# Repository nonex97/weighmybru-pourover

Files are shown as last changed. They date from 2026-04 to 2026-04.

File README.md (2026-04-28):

# WeighMyBru Pour-Over

A custom variant of the WeighMyBru² DIY espresso scale with a 1.3" SH1106 
OLED display, 3kg load cell, and a custom 3D printed enclosure.

## Documentation

📖 **[View the full documentation](https://nonex97.github.io/weighmybru-pourover/)**

For parts list, flashing guide, code changes, and print variations.

## Credits

- Original project by [031devstudios](https://weighmybru.com)
- SH1106 driver by [mlodedrwale](https://github.com/mlodedrwale/weighmybru2/tree/SH1106)

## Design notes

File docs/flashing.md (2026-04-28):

# Flashing Guide

## Prerequisites

Before starting, make sure you have the following ready:

✅ VSCode installed

✅ PlatformIO extension installed

✅ Seeed Studio XIAO ESP32S3

✅ USB-C cable (data-capable, not charge-only)

---

## Step 1 — Install Git

=== "Windows"
    Download Git from [git-scm.com](https://git-scm.com/download/win)
    and run the installer with default settings. Then verify in PowerShell:

    ```powershell
    git --version
    ```

=== "macOS"
    Using Homebrew
    ```bash
    brew install git
    ```
    Or download from [git-scm.com](https://git-scm.com/install/mac)

=== "Linux (Ubuntu/Debian)"
    
    ```bash
    sudo apt update && sudo apt install git
    ```

---

## Step 2 — Clone the Repository

Open a terminal and run:

```powershell
cd ~/Documents # or wherever you keep projects
```
```
mkdir esp32-projects
```
```
git clone -b SH1106 https://github.com/mlodedrwale/weighmybru2.git
```
```
cd weighmybru2

```

---

## Step 3 — Open in VSCode with PlatformIO

1. Launch VSCode
2. Go to **File → Open Folder**
3. Navigate to and select the `weighmybru2` folder you just cloned
4. Click **Select Folder**
5. Wait for PlatformIO to initialize — you'll see activity in the bottom status bar

---

## Step 4 — Configure `platformio.ini`

Check that the `platformio.ini` in the root of the project matches this:

```ini
[env:esp32-s3-devkitc-1]
platform = espressif32@6.12.0
board = esp32-s3-devkitc-1
framework = arduino
monitor_speed = 115200
board_upload.flash_size = 4MB
board_build.filesystem = littlefs
board_build.partitions = huge_app.csv
upload_protocol = esptool
upload_speed = 460800
upload_flags = 
	--chip=esp32s3
	--before=default_reset
	--after=hard_reset
monitor_rts = 0
monitor_dtr = 0
build_flags = 
	-DARDUINO_USB_CDC_ON_BOOT=1
	-DBOARD_HAS_PSRAM
	-Os
	-DCORE_DEBUG_LEVEL=0
lib_deps = 
	robtillaart/HX711@^0.6.0
	https://github.com/me-no-dev/ESPAsyncWebServer.git
	https://github.com/me-no-dev/AsyncTCP.git
	h2zero/NimBLE-Arduino@^1.4.0
	adafruit/Adafruit SSD1306@^2.5.7
	adafruit/Adafruit GFX Library@^1.11.9
	adafruit/Adafruit SH110X@^2.1.14
```

---
## Step 5 — Apply Code Changes

--8<-- "docs/code-changes.md"
---

## Step 6 — Connect the Board

1. Plug the XIAO ESP32S3 into your computer via USB-C
2. If the board isn't detected, put it into flash mode manually:
    - Hold **BOOT** while plugging in the USB
    - Press and release **RESET**
    - Release **BOOT**

---

## Step 7 — Find Your COM Port

In VSCode, check the **blue bottom status bar** — the COM port is listed there (e.g. `COM3` on Windows, "/dev/ttyUSB0" on Linux).

If it's not visible:

- **PlatformIO sidebar** → Devices
- **Windows:** Device Manager → Ports (COM & LPT)
- **macOS/Linux:** `ls /dev/tty*`

---

## Step 8 — Build and Upload

=== "Status Bar (Easiest)"
    - Click **✓** in the blue bottom bar to build
    - Click **→** to upload

=== "PlatformIO Sidebar"
    1. Click the PlatformIO icon (alien head) in the left sidebar
    2. Expand **PROJECT TASKS → esp32-s3-devkitc-1 → General** 
    3. Click **Build** to compile the code first
    4. **Wait for successful build** (check terminal output)
    5. Click **Upload**

=== "Terminal"
    1. **Open PlatformIO terminal:** Terminal → New Terminal
    2. **Build the project:**
    ```bash
    pio run
    ```
    3. **Upload to ESP32:**
    ```
    pio run -t upload -t uploadfs
    ```

---

## Step 8b — Upload Filesystem Image

!!! warning "Don't skip this step"
    Flashing the code alone is not enough. The web interface files are stored 
    separately in the filesystem. If you skip this step, the scale will flash 
    successfully but `weighmybru.local` will not be reachable.

After uploading the code, you need to also upload the filesystem image:

=== "PlatformIO Sidebar"
    1. Click the PlatformIO icon (alien head) in the left sidebar
    2. Expand **PROJECT TASKS → esp32-s3-devkitc-1 → Platform   **
    3. Scroll down and click **Upload Filesystem Image**
    4. Wait for the upload to complete

=== "Terminal"
    ```bash
    pio run -t uploadfs
    ```

Once both uploads are done, press the **RESET** button on the board and 
`weighmybru.local` should become reachable after connecting to the scale's WiFi.

## Step 9 — Monitor Serial Output

Click the **plug icon** in the blue status bar, or run:

```bash
pio device monitor
```

---

## Troubleshooting

??? question "Upload failing"
    - Wrong COM port — check Device Manager and verify `platformio.ini`
    - Board not in flash mode — retry the BOOT + RESET procedure
    - Driver issue — install [ESP32 USB drivers](https://www.silabs.com/developers/usb-to-uart-bridge-vcp-drivers) from Silicon Labs

??? question "Build errors"
    - Missing libraries — they'll be named in the error output; PlatformIO installs them automatically on the next build
    - Wrong board config — confirm your `platformio.ini` matches the config above exactly

??? question "Device not found"
    List connected devices
    ```bash
    pio device list
    ```
    On Linux, you might need
    ```bash
    sudo chmod 666 /dev/ttyUSB0  # or your specific device
    ```

---

## Post-Flash Setup

1. **Connect to the ESP32's WiFi access point** (check serial monitor for details - AP IP :192.168.4.1)
2. **Access the web interface** for calibration and configuration
3. **Configure your home WiFi** through the web interface

---

## Success Indicators
✅ Build completes without errors

✅ Upload shows "SUCCESS" message

✅ Serial monitor shows boot messages

✅ ESP32 creates WiFi access point (for initial setup)

Your WeighMyBru scale should now be running! Check the serial monitor for the web interface URL and initial setup instructions.

## Next Steps — Calibration

With the firmware flashed and the scale booting correctly, the last step 
is to calibrate the scale.

The calibration process for this build is identical to the original 
WeighMyBru², so follow the official guide:

👉 [WeighMyBru Calibration Guide](https://weighmybru.com/guides/calibration-guide/)

## Hardcoding WiFi Credentials (Optional)

!!! note "Only do this if the access point is not showing up"
    In most cases the scale will create a WiFi access point on first boot 
    and you can configure credentials through the web interface. Only follow 
    these steps if no access point appears and the serial monitor is showing 
    WiFi-related errors on boot.

### Step 1 — Open `main.cpp`

In VSCode, open `src/main.cpp` and find the `#include` block at the top of 
the file. Add these two lines directly after it:

```cpp
static const char* hardcode_ssid = "YOUR_SSID";
static const char* hardcode_password = "YOUR_PASSWORD";
```

Replace `YOUR_SSID` and `YOUR_PASSWORD` with your actual WiFi network name 
and password.

### Step 2 — Find the WiFi Sleep Lines

Scroll down in `main.cpp` until you find these two lines (around line 108):

```cpp { .no-copy }
WiFi.setSleep(true);
Serial.println("WiFi power management enabled for battery optimization");
```

Add the following line immediately after them:

```cpp
saveWiFiCredentials(hardcode_ssid, hardcode_password);
```

### Step 3 — Re-flash

Save the file, then repeat **Step 7** (Build and Upload). The scale will now connect directly to your 
WiFi network on boot instead of creating an access point.

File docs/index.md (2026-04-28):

# WeighMyBru Pour-Over

A custom variant of the [WeighMyBru²](https://weighmybru.com) DIY espresso scale, 
redesigned for pour-over brewing with a custom 3D printed enclosure, 
a 1.3" SH1106 OLED display, and a 3kg load cell.

---

## Credits

- **WeighMyBru²** original project by [031devstudios](https://weighmybru.com)
- **SH1106 display driver** implementation by 
  [mlodedrwale](https://github.com/mlodedrwale/weighmybru2/tree/SH1106) — 
  this build would not have been possible without their work on SH1106 support.

## What's Different in This Build

- **Display:** 1.3" SH1106 OLED
- **Load cell:** 3kg load cell
- **Enclosure:** Bigger body dimensions (140x100x29mm)

---

## Print Versions

There are two sets of choices when printing this build — pick one from each.

### Enclosure Mounting

| Version | Description | Best for |
|---|---|---|
| **Heat-set (not tested)** | Uses M3x5x4 brass heat-set inserts for threaded mounting | Stronger, survives repeated disassembly |
| **Self-tapping (tested)** | Screws drive directly into the plastic | Simpler build, no soldering iron or heat inserts needed |

### Screen Cutout Fit

| Version | Description | Best for |
|---|---|---|
| **Normal (tested)** | Standard fit for the OLED screen | Most printers |
| **Loose (not tested)** | 1mm extra clearance on all sides | If the screen is a tight fit on your print |

### Not Sure Which Fit to Use?

Before printing the full enclosure, print the **display fit test** first — 
it's a small piece that only takes around 20 minutes and lets you check whether 
the Normal or Loose fit works better for your specific screen and printer.

!!! tip "Always test before printing the full enclosure"
    Download the test print, check if your screen sits flush and stable, 
    then choose your version accordingly. The full top plate takes much 
    longer to print and filament is worth saving!

| Test Print | For |
|---|-----|
| Display Fit Test - Normal | Standard fit |
| Display Fit Test - Loose | Loose fit |

STL files for the test prints are in the [`/step/display-fit-test`](https://github.com/nonex97/weighmybru-pourover/tree/main/step/display-fit-test) folder of this repo.

## Getting Started

1. [Parts List](parts-list.md) — everything you need with links
2. [Flashing Guide](flashing.md) — how to flash the firmware to your board
3. [Code Changes](code-changes.md) — what to configure before compiling from source

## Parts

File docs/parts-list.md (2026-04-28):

# Parts List

Items marked with ⚠️ differ from the original WeighMyBru² build.

| Qty | Item | Link |
|-----|---|---|
| 1 | 3kg Load Cell ⚠️ | [Buy](https://de.aliexpress.com/item/1005007785358444.html) |
| 1 | HX711 | [Buy](https://de.aliexpress.com/item/1005009765229699.html) |
| 1 | Seeed Studio XIAO ESP32S3 | [Buy](https://de.aliexpress.com/item/1005006987905528.html) |
| 2 | Capacitive Touch Pads | [Buy](https://de.aliexpress.com/item/1005010406553525.html) |
| 1 | 1.3" SH1106 OLED Display ⚠️ | [Buy](https://de.aliexpress.com/item/1005010183965559.html) |
| 1 | JST-PH 2.0 Male Connector | [Buy](https://de.aliexpress.com/item/1005008684370279.html) |
| 1 | Slide Switch (5mm) | [Buy](https://de.aliexpress.com/item/1005008330569768.html) |
| 1 | 22AWG Hookup Wire | [Buy](https://de.aliexpress.com/item/1005006250522147.html) |
| 2 | (Optional) M4x6x4 Heat Set Inserts ⚠️ | [Buy](https://de.aliexpress.com/item/1005008666672949.html) |
| 16 | M1.7x4 Self Tapping Screws | [Buy](https://de.aliexpress.com/item/1005009385119995.html) |
| 2 | M4x16 Button Head Screws ⚠️ | [Buy](https://de.aliexpress.com/item/1005008512900059.html) |
| 2 | M5x16 Button Head Screws ⚠️ | [Buy](https://de.aliexpress.com/item/1005008512900059.html) |
| 2 | 100K ohm 1% 1/4W Resistors | [Buy](https://de.aliexpress.com/item/1005003923602966.html) |
| 1 | 3.7V JST-2.0 Li-ion Battery (Up to 50x30mm) |  |
| 4 | Self-Adhesive Rubber Feet |  |
| 1 | Double Sided Tape (to hold battery) |  |

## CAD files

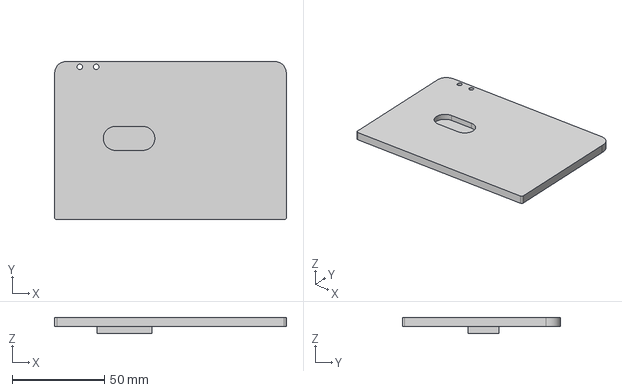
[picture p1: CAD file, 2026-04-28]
step/body/WeighMyBru² - Bottom Supported.step
126.0 x 86.0 x 8.80 mm

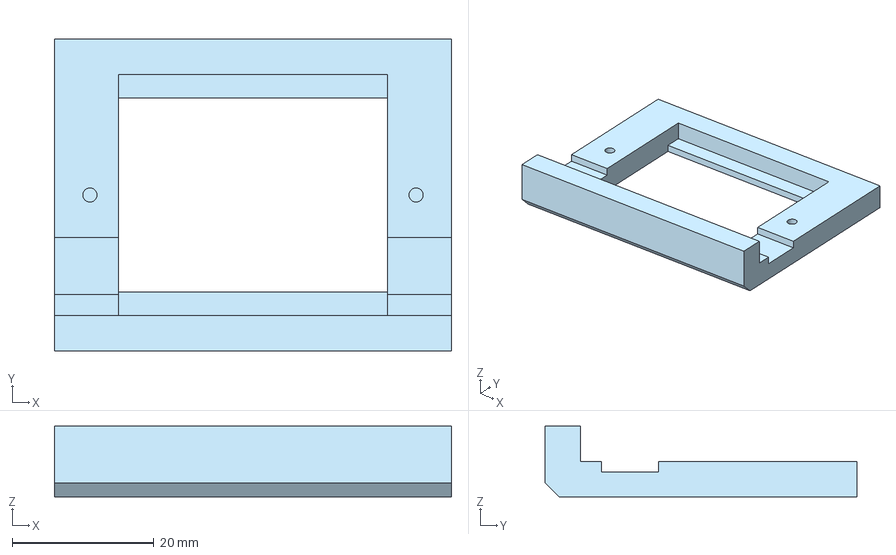
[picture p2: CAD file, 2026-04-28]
step/display-fit-test/Display Fit Test - Loose.step
56.0 x 44.0 x 10.0 mm

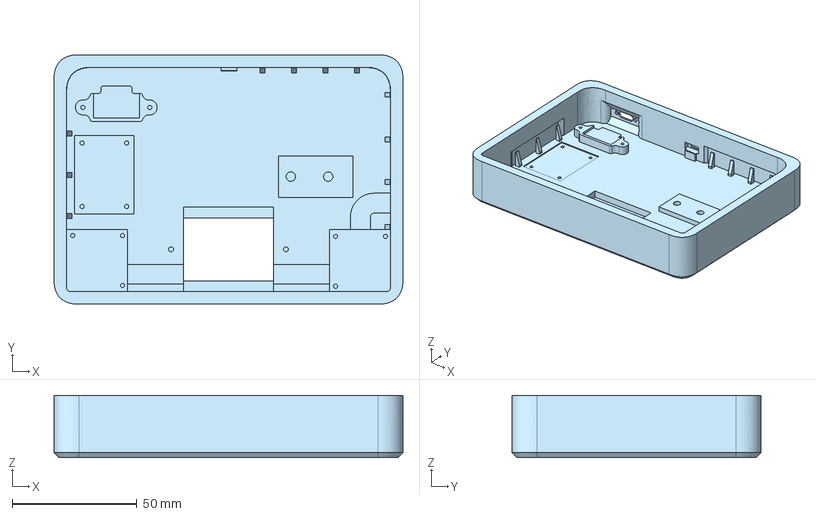
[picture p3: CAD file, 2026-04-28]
step/top-plate/WeighMyBru² - Top (0.8mm) - Self tapping.step
140.0 x 100.0 x 25.0 mm

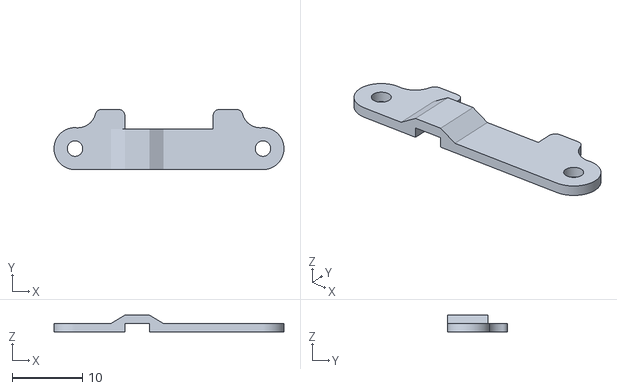
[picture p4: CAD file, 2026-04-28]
step/body/WeighMyBru²- XIAO Clamp.stl
32.8 x 8.60 x 2.40

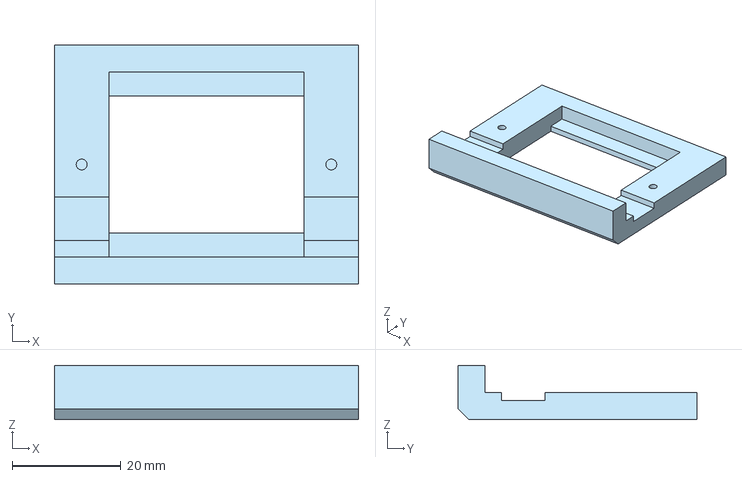
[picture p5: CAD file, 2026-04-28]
step/display-fit-test/Display Fit Test - Normal.step
56.0 x 44.0 x 10.0 mm

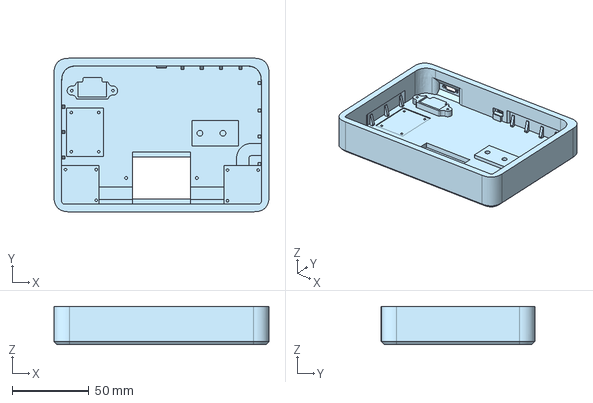
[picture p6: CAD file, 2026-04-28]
step/top-plate/WeighMyBru² - Top (0.8mm) - Self tapping [Loose fit].step
140.0 x 100.0 x 25.0 mm

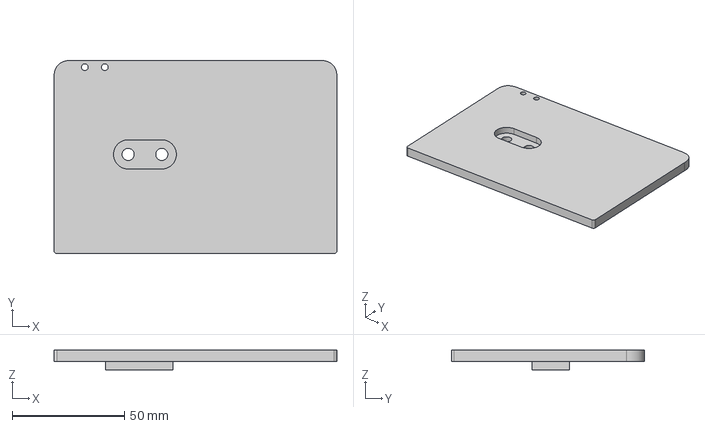
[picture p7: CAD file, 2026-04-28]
step/body/WeighMyBru² - Bottom.step
126.0 x 86.0 x 8.80 mm

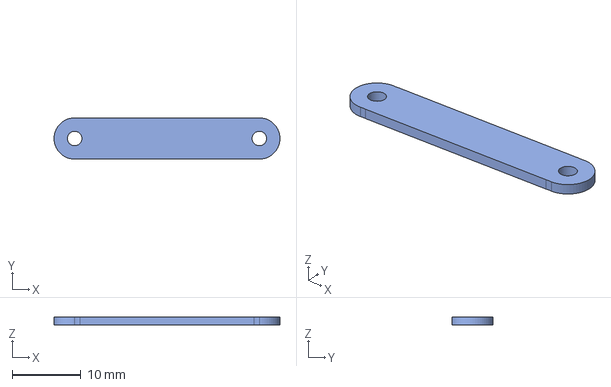
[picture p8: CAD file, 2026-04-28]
step/body/WeighMyBru²- ESP32 Clamp.step
32.8 x 6.00 x 1.20 mm

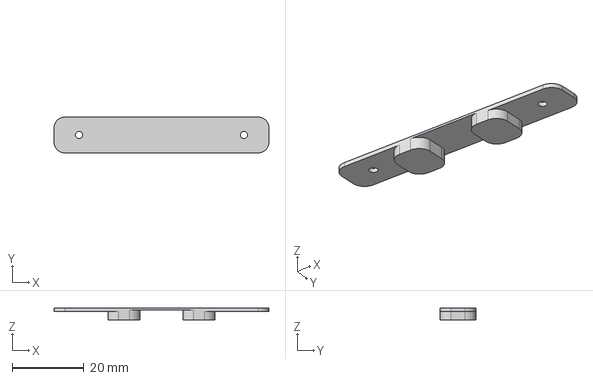
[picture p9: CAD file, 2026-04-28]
step/body/WeighMyBru² - Screen Clamp.step
60.0 x 10.0 x 3.30 mm

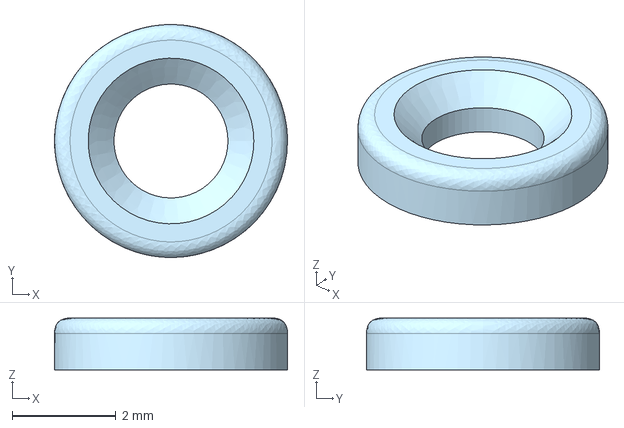
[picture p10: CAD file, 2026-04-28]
step/body/WeighMyBru² - M2 Washer.step
4.50 x 4.50 x 1.00 mm

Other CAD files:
step/top-plate/WeighMyBru² - Top (0.8mm) - Heat insert.step
step/top-plate/WeighMyBru² - Top (0.8mm) - Heat insert [Loose fit].step

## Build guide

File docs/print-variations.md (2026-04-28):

# Print Variations

## Choosing Your Version

Before printing, you need to make two choices:

### Mounting Style

| Version | Description |
|---|---|
| **Heat-set** | M4x6x4 brass inserts pressed into the enclosure | 
| **Self-tapping** | Screws drive directly into the plastic |

### Screen Cutout Fit

| Version | Description |
|---|---|
| **Normal** | Standard clearance for the SH1106 display |
| **Loose (+1mm)** | 1mm extra on all sides — use if the screen is too tight |

!!! tip "Print the fit test first"
    Before committing to the full top plate print, print the display fit 
    test piece first. It takes only a few minutes and lets you confirm 
    which fit version works best for your printer and tolerances.

## STEP Files

All files are available in the [`/step`](https://github.com/nonex97/weighmybru-pourover/tree/main/step) folder of this repository.

| File | Description |
|---|---|
| `Display Fit Test — Normal` | Test piece, standard fit |
| `Display Fit Test — Loose (+1mm)` | Test piece, loose fit |
| `WeighMyBru² - Top (0.8mm) - Heat insert` | Top plate, heat insert version |
| `WeighMyBru² - Top (0.8mm) - Heat insert [Loose fit]` | Top plate, heat insert, loose fit |
| `WeighMyBru² - Top (0.8mm) - Self Tapping` | Top plate, self-tapping version |
| `WeighMyBru² - Top (0.8mm) - Self Tapping [Loose fit]` | Top plate, self-tapping, loose fit |
| `WeighMyBru² - Bottom` | Bottom enclosure — enable supports in slicer |
| `WeighMyBru² - Bottom Supported` | Bottom enclosure — 0.1mm built-in support surface around screw holes, no slicer supports needed |

!!! info
    All remaining files are identical regardless of which 
    mounting style or fit version you choose.

## 3D Printing Settings

For print settings (layer height, infill, supports etc.), the original 
WeighMyBru² printing guide applies directly to this build:

👉 [WeighMyBru² 3D Printing Guide](https://weighmybru.com/guides/assembly-guide/)

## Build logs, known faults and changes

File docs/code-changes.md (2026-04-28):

# Code Changes

The original WeighMyBru² firmware needs a few small changes to work with 
the hardware used in this build.

---

## Required Changes

### 1. Display Controller — `config.h` (line 20)

Change from:

```cpp { .no-copy }
#define DISPLAY_CONTROLLER DISPLAY_CONTROLLER_SSD1306
```

To:

```cpp
#define DISPLAY_CONTROLLER DISPLAY_CONTROLLER_SH1106
```

---

### 2. Display Height — `config.h` (line 24)

Change from:

```cpp { .no-copy }
#define DISPLAY_HEIGHT DISPLAY_HEIGHT_32
```

To:

```cpp
#define DISPLAY_HEIGHT DISPLAY_HEIGHT_64
```

---

### 3. Display Rotation — `SH1106Driver.h` (line 23)

Change from:

```cpp { .no-copy }
oled.setRotation(2);
```

To:

```cpp
oled.setRotation(0);
```

!!! note "Display upside down?"
    If the display appears upside down after flashing, change the value 
    back from `0` to `2`.

---

## Optional Changes

### Always-On Battery Percentage — `DisplayLayout.h`

By default the battery percentage is not permanently shown on the display. 
To add it, find line 152 in `DisplayLayout.h`:

```cpp { .no-copy }
// display.print("WI");
```

Add the following block immediately after it:

```cpp
// BATTERY PERCENTAGE
        display.setFont(&FreeMonoBold9pt7b);
        display.setTextSize(1);
        String batteryStr = String(st.batteryPercent) + "%";

        // Calculate text width for right alignment
        int16_t x1, y1;
        uint16_t w, h;
        display.getTextBounds(batteryStr, 0, 0, &x1, &y1, &w, &h);

        // Right-align: set cursor so the text ends at DISPLAY_WIDTH (128)
        int cursorX = DISPLAY_WIDTH - w - 2;
        display.setCursor(cursorX, 57);

        // Blink if battery < 10%
        if (st.batteryPercent < 10) {
            if ((millis() / 500) % 2 == 0) { // Show only every other 500ms
                display.print(batteryStr);
            }
        } else {
            display.print(batteryStr);
        }
```

This renders the battery percentage right-aligned at the bottom of the 
display, and blinks it when the battery drops below 10%.
